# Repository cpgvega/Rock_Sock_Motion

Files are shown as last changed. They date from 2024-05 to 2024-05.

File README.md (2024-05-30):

# Rock'em Sock'em Motion

## Authors
- [Jonathan Meng] - [mengjc@umich.edu](mailto:mengjc@umich.edu)
- [Christian Reed] - [chrireed@umich.edu](mailto:chrireed@umich.edu)
- [Christian Vega](https://github.com/cpgvega) - [email@example.com](mailto:cpvega@umich.edu)

## Prerequisites/Materials
- STMicroelectronics Nucleo Board - L4R5ZI
- STMicroelectronics Nucleo Board - F446RE
- Servo Motors
- Bread boards
- Wiring
- [H-Bridge](https://www.amazon.com/Driver-Module-H-Bridge-Stepper-Control/dp/B07RWLKCH3)
- [Door Lock Actuator](https://www.amazon.com/Zone-2-Pack-Universal-Power-Actuator/dp/B00PWLJ2OC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)
- [DDR PS2 Pad](https://www.amazon.com/Dance-Revolution-Regular-Playstation2-Playstation-2/dp/B000GF7KAW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)
- [XBee Moduel](https://www.amazon.com/Module-Upgrade-Zigbee-Wireless-Transmission/dp/B0CP78Y1BF)

## Member Contribution
### Jonathan Meng
1.	Servo calibration and Pulse Width Modulation Set-Up
2.	Software for UART and Start Button Functionality
3.	Code Integration of Individual Software Components into Final Project
4.	Accelerometer and XBee ADC Integration and Debugging
5.	Mechanical Design and System Integration of Servos
6.	Mechanical Design and System Integration of DC Stepper Motors
7.	Mechanical Design and System Integration of Rock ‘Em Sock ‘Em Platform
8.	XBee Setup and Communication Protocol Debugging
9.	UART Debug, TX/RX System Integration, and STMBoard Testing
10.	Accelerometer and XBee ADC Integration and Debugging
11.	STMBoard Integration and Pinout Discovery
12.	Software for UART and Start Button Functionality

### Christian Reed
1.	H-Bridge and DC Stepper Motor Integration
2.	Servo calibration and Pulse Width Modulation Set-Up
3.	Mechanical Design and System Integration of PS2 DDR Pad
4.	Mechanical Design and System Integration of Servos
5.	Mechanical Design and System Integration of DC Stepper Motors
6.	Circuit Building of Hand-Held Accelerometers
7.	Accelerometer and XBee ADC Integration and Debugging
8.	Software for XBee Communication and PS2 Functionality
9.	Software for UART and Start Button Functionality
10.	XBee Setup and Communication Protocol Debugging
11.	Accelerometer and XBee ADC Integration and Debugging
12.	STMBoard Integration and Pinout Discovery

### Christian Vega
1.	Mounting of Hardware
2.	Schematic Diagramming
3.	H-Bridge and DC Stepper Motor Integration
4.	Mechanical Design and System Integration of PS2 DDR Pad
5.	Software for PS2 Polling and Bit Extraction
6.	Mechanical Design and System Integration of Servos
7.	Mechanical Design and System Integration of DC Stepper Motors
8.	Mechanical Design and System Integration of Rock ‘Em Sock ‘Em Platform
9.	System Integration of PS2 DDR Pad
10.	CAD, 3D Printing, and System Integration of Hand-Held Accelerometers
11.	STMBoard Integration and Pinout Discovery
12.	Software for PS2 Polling and Bit Extraction

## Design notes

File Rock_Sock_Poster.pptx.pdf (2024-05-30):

# Rock’ Sock’ and otion

## Christian Reed, Christian Vega, Jonathan Meng

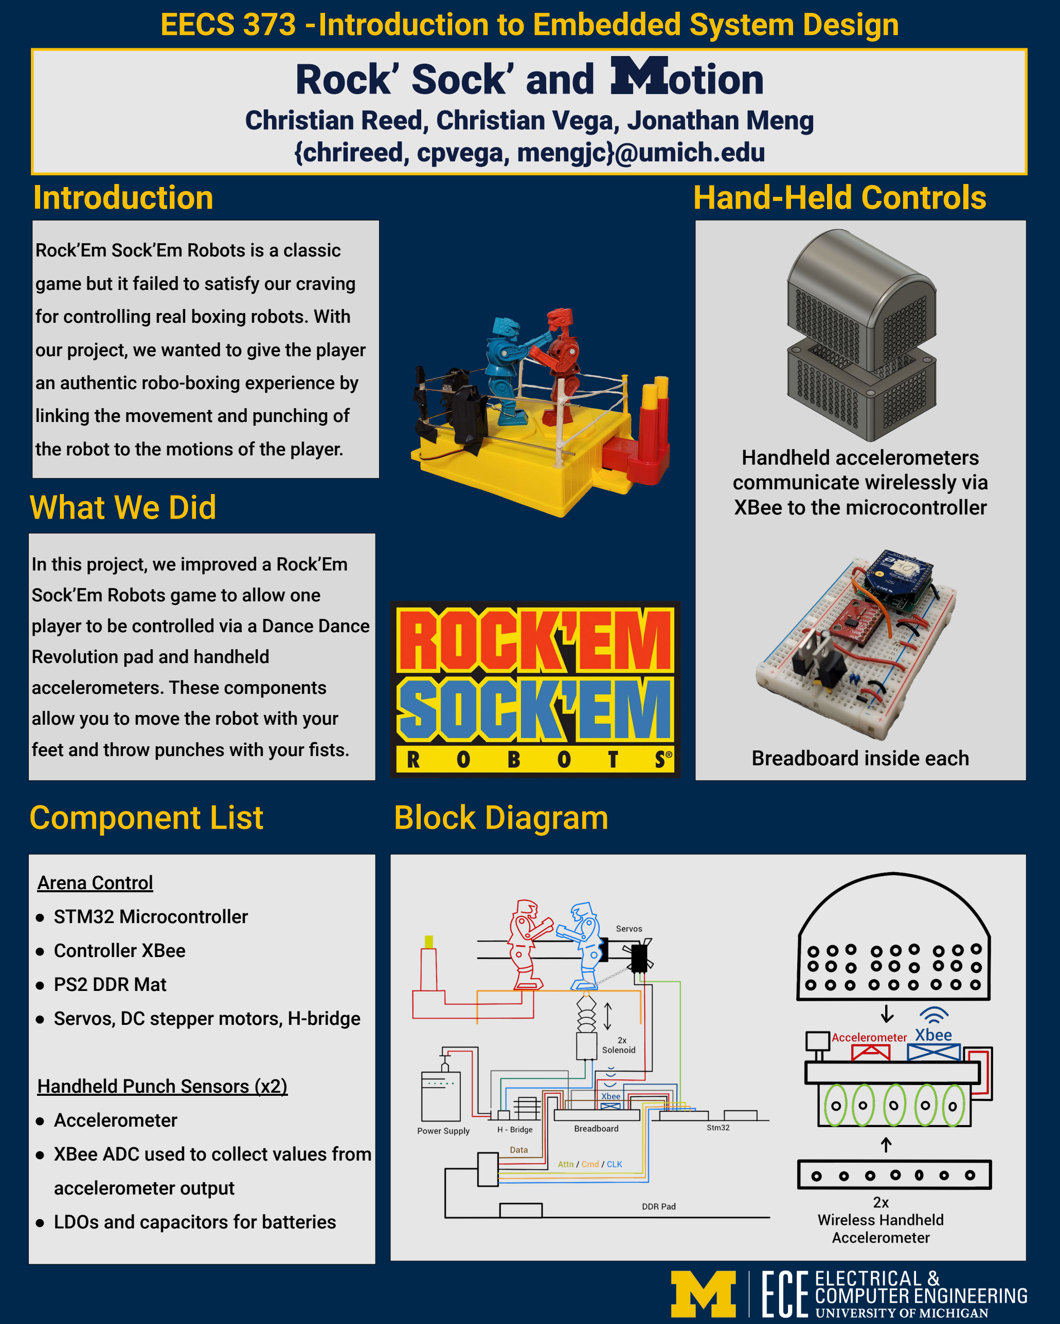
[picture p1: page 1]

## {chrireed, cpvega, mengjc}@umich.edu

# EECS 373 -Introduction to Embedded System Design

# Introduction

Component List | Block Diagram

# What We Did

Handheld accelerometers
communicate wirelessly via XBee to the microcontroller

Rock’Em Sock’Em Robots is a classic

game but it failed to satisfy our craving

for controlling real boxing robots. With

our project, we wanted to give the player

an authentic robo-boxing experience by

linking the movement and punching of

the robot to the motions of the player.

# Hand-Held Controls

In this project, we improved a Rock’Em Sock’Em Robots game to allow one player to be controlled via a Dance Dance Revolution pad and handheld accelerometers. These components allow you to move the robot with your feet and throw punches with your fists.

Arena Control

- STM32 Microcontroller
- Controller XBee
- PS2 DDR Mat
- Servos, DC stepper motors, H-bridge

Handheld Punch Sensors (x2)

- Accelerometer
- XBee ADC used to collect values from

accelerometer output

- LDOs and capacitors for batteries

Breadboard inside each

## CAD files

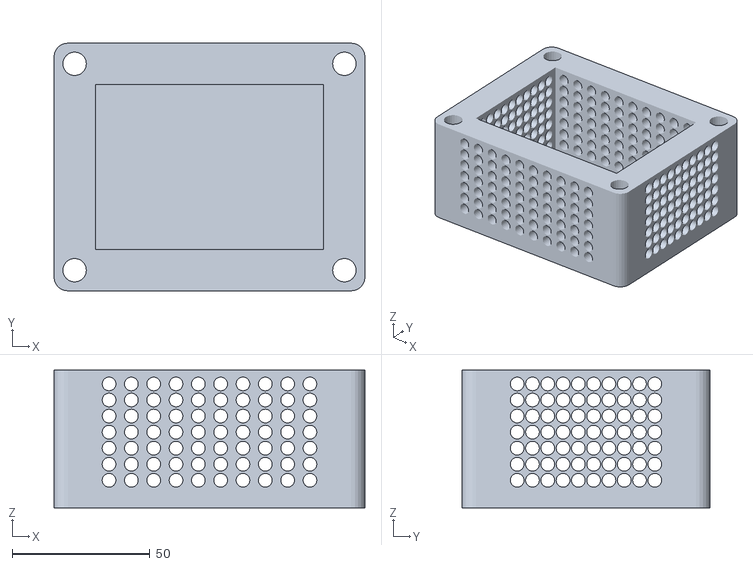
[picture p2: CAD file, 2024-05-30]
CAD Designs/Capsule_Accelorometer v9.obj
113.0 x 90.0 x 50.0

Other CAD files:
CAD Designs/RSM_3d_model v1.f3d

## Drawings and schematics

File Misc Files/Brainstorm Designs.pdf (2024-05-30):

# Brainstorm Designs

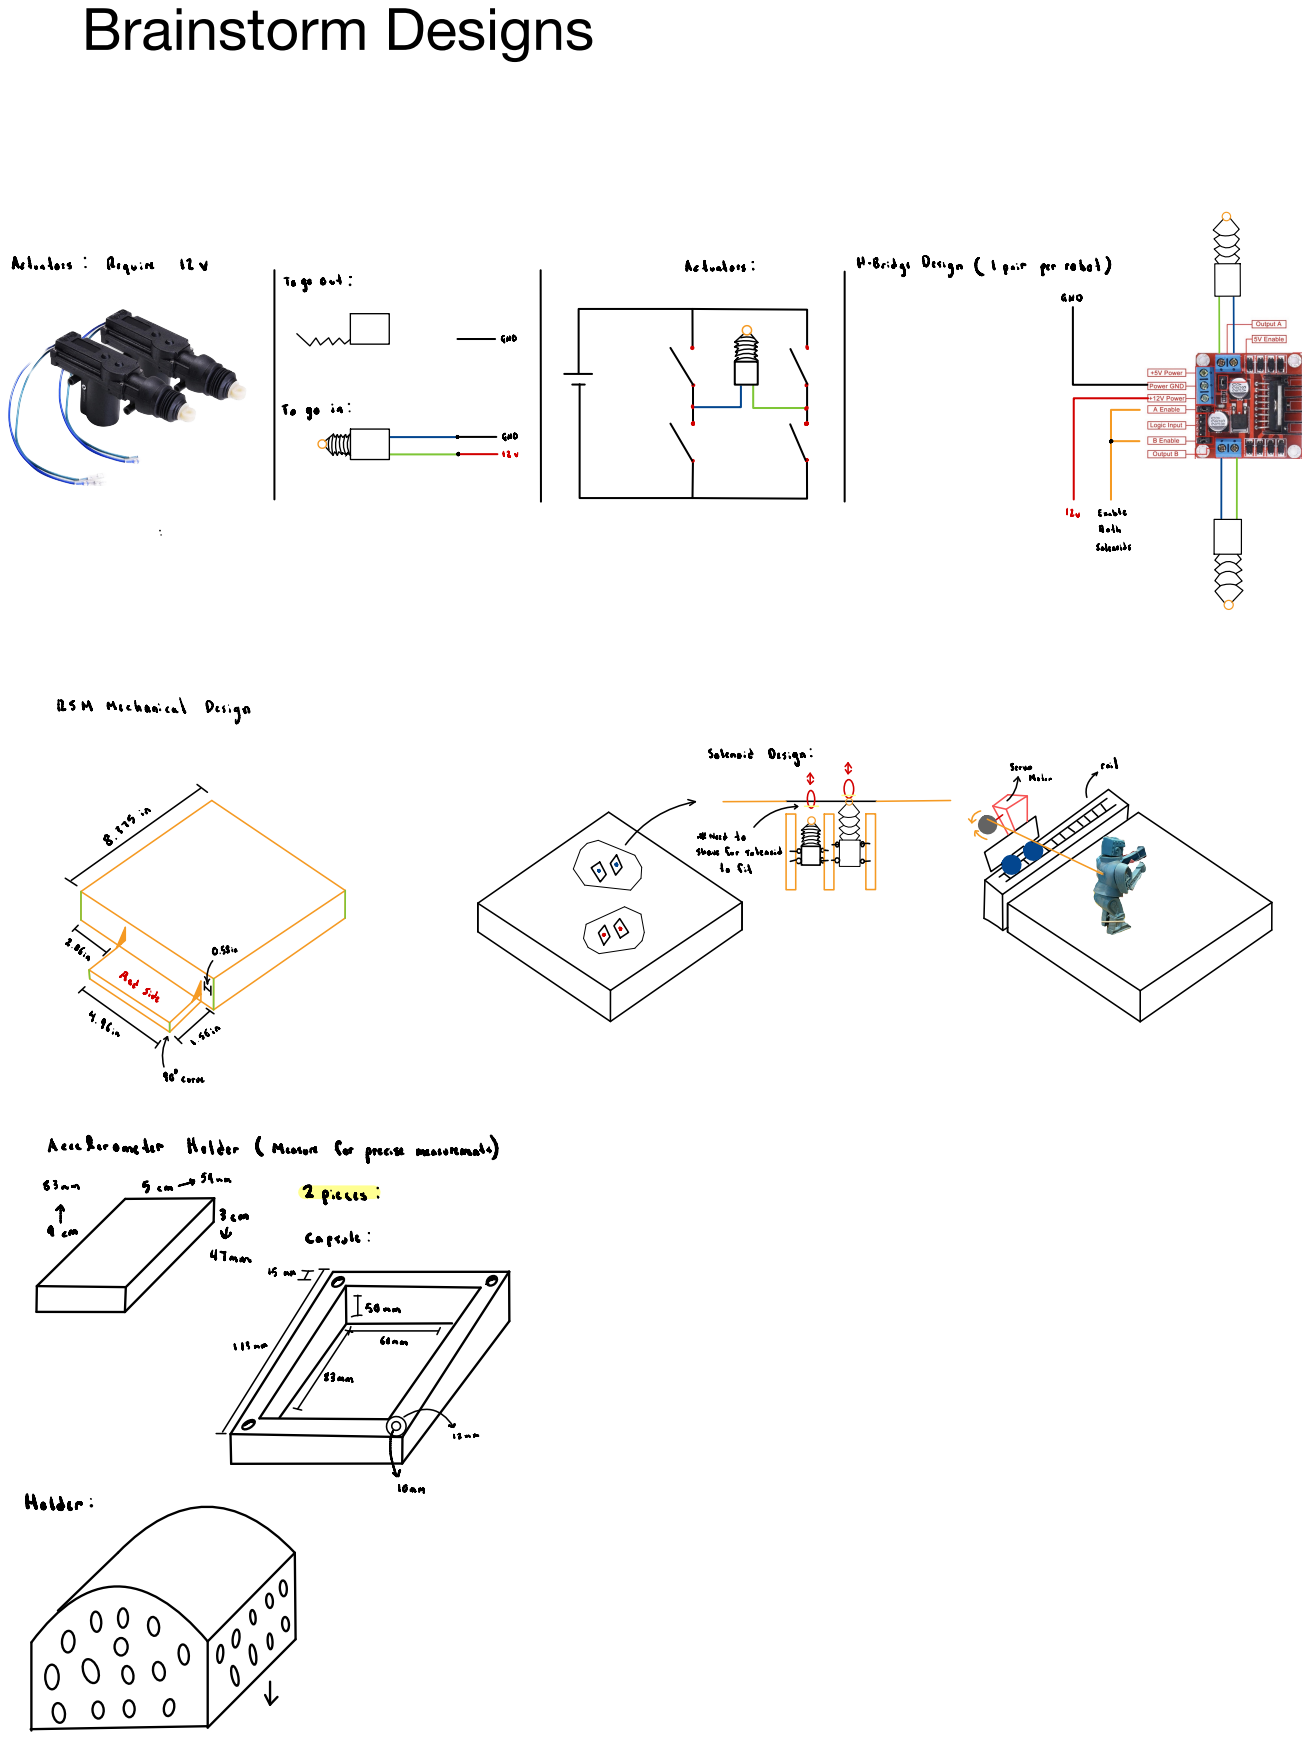
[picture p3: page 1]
Actuators :; Require; H-Bridge Design (1 pair per robot) To go out :; GND; Enable; Both .; Solenoids; Mechanical Design; Solenoid; Design :; Serve; rail; Motor; to Sit; ↳sim; goo curve; 83 man; 2 pieces :; Capsule :; Holder :

* Need to
Shave for solenoid

Accelerometer Holder (Measure for precise measurements)

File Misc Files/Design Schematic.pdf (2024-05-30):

# Design Schematic

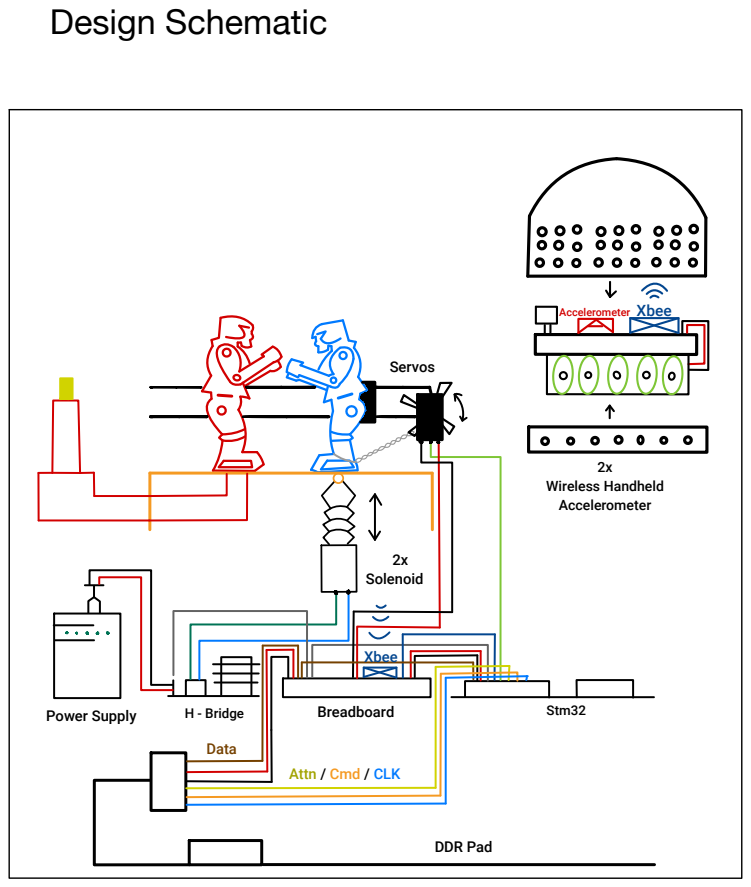
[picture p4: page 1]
Power Supply; H - Bridge; Breadboard; Stm32; 2x Solenoid; Servos; DDR Pad; Data; Xbee; 2x Wireless Handheld Accelerometer; Accelerometer

Attn / Cmd / CLK

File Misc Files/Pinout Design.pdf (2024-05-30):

# Stm32 Wall

# Outlet

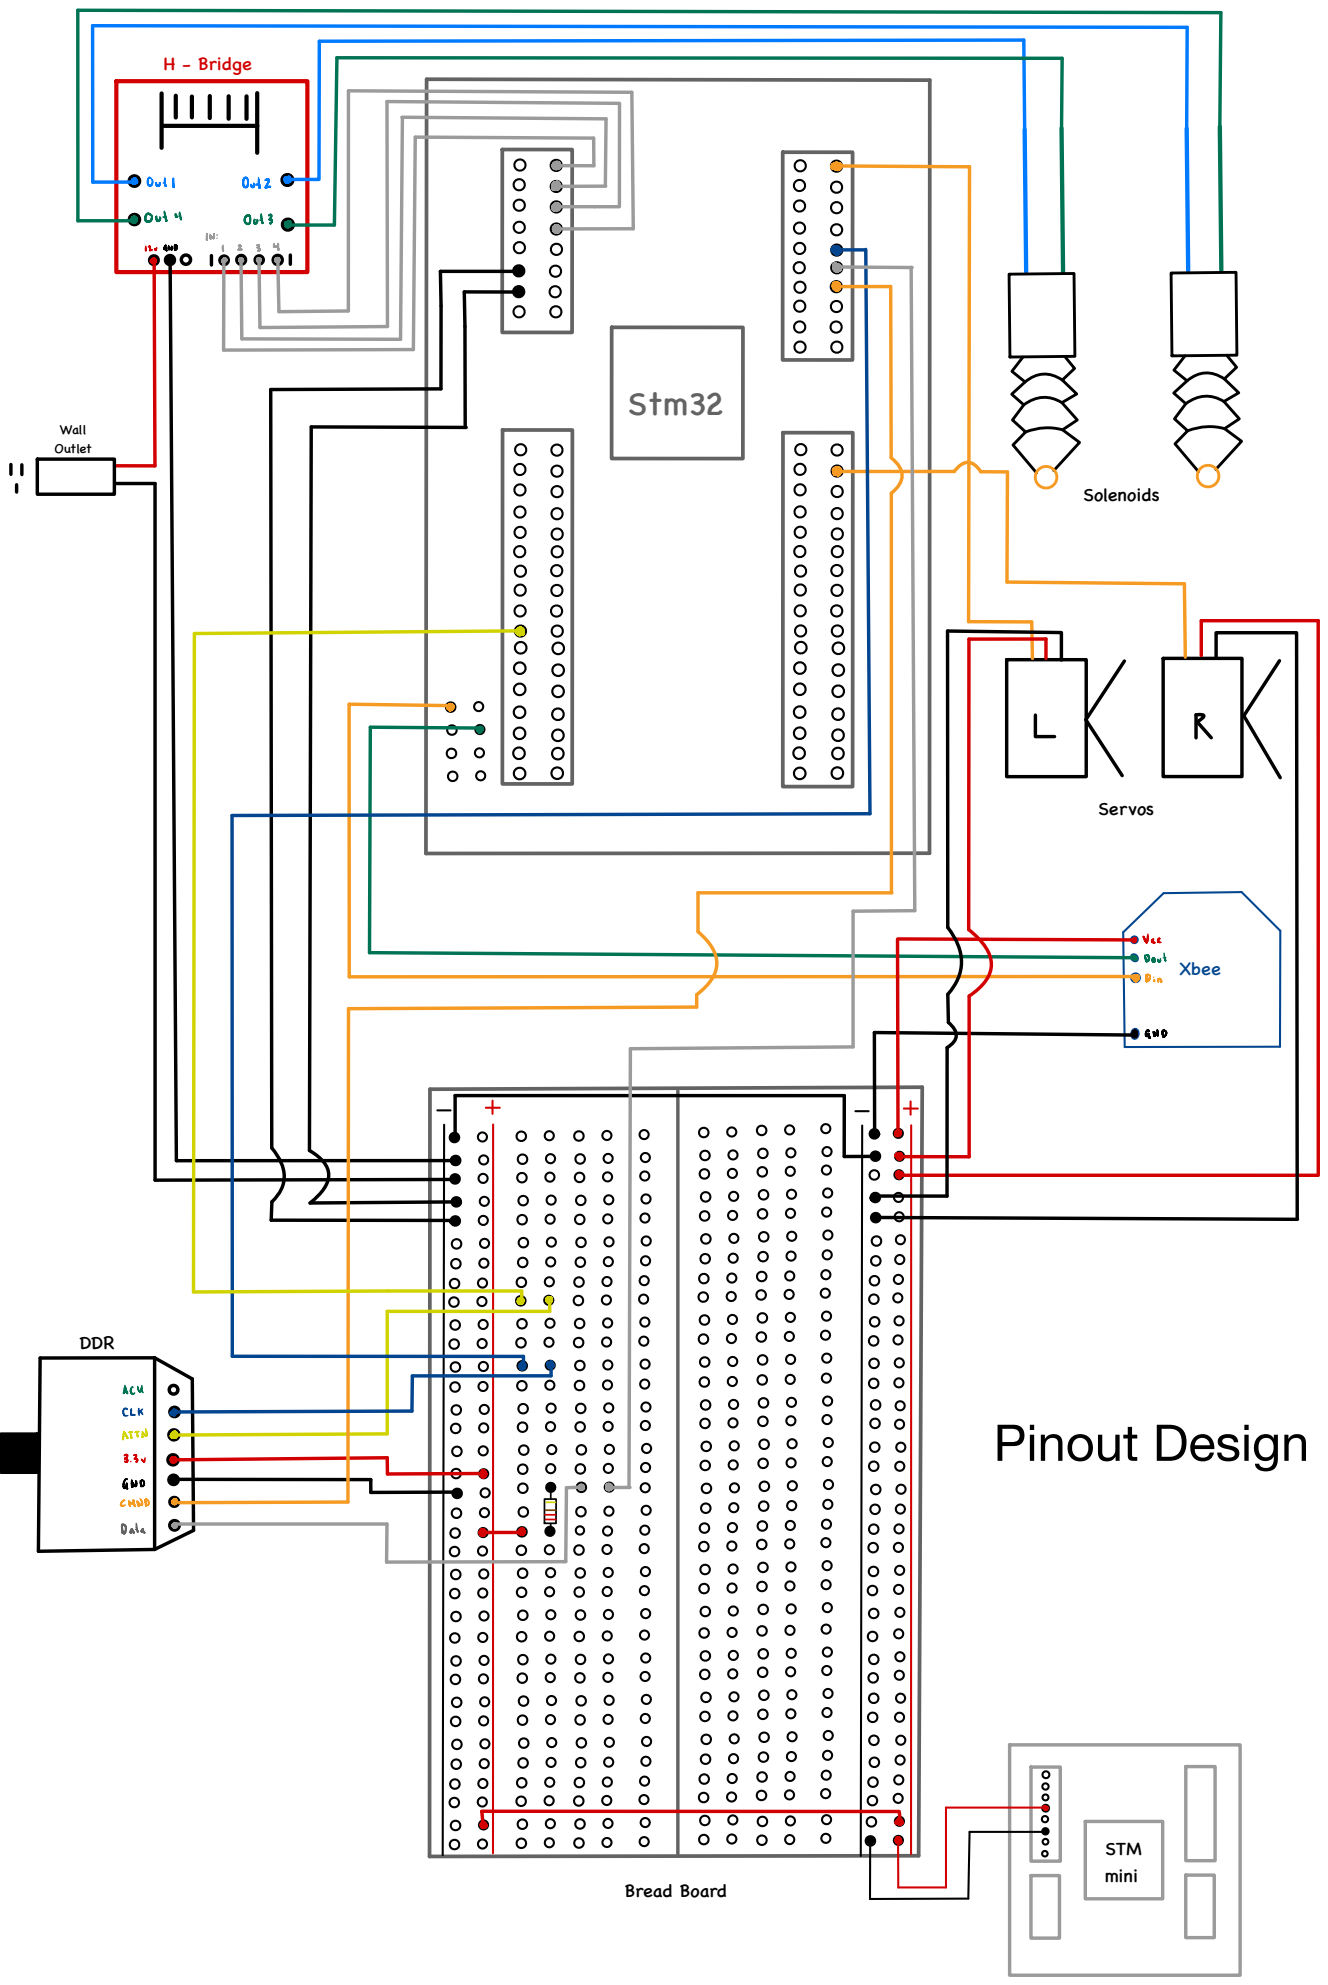
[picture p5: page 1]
Xbee; STM mini; H - Bridge; Solenoids; Bread Board; Servos; DDR; Pinout Design; Out1; Out &; · Out 4; Out 38; 12v GND; · Dout; ⑧ Din; · GND; CLK; ATTN; GND; CMND; Data

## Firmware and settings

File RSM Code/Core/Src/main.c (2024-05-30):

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
/* Includes ------------------------------------------------------------------*/
#include "main.h"

SPI_HandleTypeDef hspi1;

TIM_HandleTypeDef htim1;
TIM_HandleTypeDef htim4;

UART_HandleTypeDef huart1;

/* USER CODE BEGIN PV */
// First 5 bytes of DDR pad -> 01 - 03: Header (Will Not Change) & 04 - 05: Digital BTN Values
uint8_t ddr_tx[5] =  {0x01, 0x42, 0x00, 0x00, 0x00};
uint8_t ddr_rx[5];
// ddr pad buffer for eliminating noise (update both when changing)
int ddr_buf_size = 4;
char ddr_buf[4];

int num_u = 0;
int num_d = 0;
int num_l = 0;
int num_r = 0;
int num_s = 0;
int num_x = 0;

int uart_tx_size = 19;
int uart_rx_size = 24;
int punchThreshold = 750;
int leftPunch = 0;
int rightPunch = 0;
int leftPunchDone = 1;
int rightPunchDone = 1;
/* USER CODE END PV */

void SystemClock_Config(void);
static void MX_GPIO_Init(void);
static void MX_SPI1_Init(void);
static void MX_TIM4_Init(void);
static void MX_TIM1_Init(void);
static void MX_USART1_UART_Init(void);
/* USER CODE BEGIN 0 */

/*
 * poll_accell: sends a polling instruction to one of the two handheld XBEE
 * + accelerometer combos. The XBEE returns a packet of data which poll_accel
 * parses and returns the ADC value from the accelerometer
 * */
int poll_accel(uint8_t tx_buf[]){
	uint8_t rx_buf[uart_rx_size];
	//HAL_GPIO_WritePin(GPIOC, GPIO_PIN_9, GPIO_PIN_RESET);
	HAL_StatusTypeDef valT = HAL_UART_Transmit(&huart1, &tx_buf[0], uart_tx_size, 50);
	HAL_StatusTypeDef valR = HAL_UART_Receive(&huart1, &rx_buf[0], uart_rx_size, 100);
	if(valR == HAL_TIMEOUT) {
		//Debug using GPIO
		//HAL_GPIO_WritePin(GPIOC, GPIO_PIN_9, GPIO_PIN_SET);
		/*
		 * Occasionally the XBEE will give garbled data that sends UART into
		 * an infinite timeout loop, these statements are used to reset it
		*/
		HAL_UART_DeInit(&huart1);
		HAL_UART_Init(&huart1);
		return 0;
	}
	return (rx_buf[uart_rx_size - 3] << 8 | rx_buf[uart_rx_size - 2]);
}


// used by punch_logic to activate the left, right, or left and right solenoids
void punch(int left, int right) {
	if(right) {
		HAL_GPIO_WritePin(GPIOC, GPIO_PIN_9, GPIO_PIN_RESET);
		HAL_GPIO_WritePin(GPIOC, GPIO_PIN_8, GPIO_PIN_SET);
	}
	if(left){
		HAL_GPIO_WritePin(GPIOC, GPIO_PIN_11, GPIO_PIN_RESET);
		HAL_GPIO_WritePin(GPIOC, GPIO_PIN_10, GPIO_PIN_SET);
	}
	HAL_Delay(40);
	if(right) {
		HAL_GPIO_WritePin(GPIOC, GPIO_PIN_8, GPIO_PIN_RESET);
		HAL_GPIO_WritePin(GPIOC, GPIO_PIN_9, GPIO_PIN_SET);
	}
	if(left) {
		HAL_GPIO_WritePin(GPIOC, GPIO_PIN_10, GPIO_PIN_RESET);
		HAL_GPIO_WritePin(GPIOC, GPIO_PIN_11, GPIO_PIN_SET);
	}
	HAL_Delay(100);
	HAL_GPIO_WritePin(GPIOC, GPIO_PIN_8, GPIO_PIN_RESET);
	HAL_GPIO_WritePin(GPIOC, GPIO_PIN_9, GPIO_PIN_RESET);
	HAL_GPIO_WritePin(GPIOC, GPIO_PIN_10, GPIO_PIN_RESET);
	HAL_GPIO_WritePin(GPIOC, GPIO_PIN_11, GPIO_PIN_RESET);
	leftPunch = 0;
	rightPunch = 0;
	return;
}

// takes in the left and right accel values and activates solenoids using punch
void punch_logic(int left_accel_val, int right_accel_val) {
	if(leftPunchDone) {
				if(left_accel_val > punchThreshold) {
					leftPunch = 1;
					leftPunchDone = 0;
				}
			} else {
				if(left_accel_val < punchThreshold) {
					leftPunchDone = 1;
				}
			}
			if(rightPunchDone) {
				if(right_accel_val > punchThreshold) {
					rightPunch = 1;
					rightPunchDone = 0;
				}
			} else {
				if(right_accel_val < punchThreshold) {
					rightPunchDone = 1;
				}
			}

			if (leftPunch | rightPunch) {
				punch(leftPunch, rightPunch);
			}
	return;
}

/*
 * This functions breaks down the 4th byte extracted from the DDR pad
 * and return a char of the designated direction
 */
char bit_extract (uint8_t ddr_byte_3, uint8_t ddr_byte_4) {
	// Grab up
	uint8_t up = (ddr_byte_3 << 3) >> 7;
	uint8_t right = (ddr_byte_3 << 2) >> 7;
	uint8_t left = (ddr_byte_3 << 0) >> 7;
	uint8_t down = (ddr_byte_3 << 1) >> 7;
	uint8_t circ = (ddr_byte_4 << 2) >> 7;

	up &= (0b1);
	right &= (0b1);
	left &= (0b1);
	down &= (0b1);
	circ &= (0b1);
	if (!circ)
		return 's';
	else if(!up)
		return 'u';
	else if (!right)
		return 'r';
	else if (!left)
		return 'l';
	else if (!down)
		return 'd';

	return 'x';
}

// polls the ddr pad and loads result in ddr_rx
char poll_ddr(){
	// DDR Pad Data Request - These values (ddr_rx[4] & ddr_rx[5] will be used for the movement)
	// RESET ATTN line before sent/receive
	HAL_GPIO_WritePin(GPIOB, GPIO_PIN_6, GPIO_PIN_RESET);

	// Transmit/Receive byte by byte
	HAL_SPI_TransmitReceive(&hspi1, &ddr_tx[0], &ddr_rx[0], 1, 100);
	HAL_SPI_TransmitReceive(&hspi1, &ddr_tx[1], &ddr_rx[1], 1, 100);
	HAL_SPI_TransmitReceive(&hspi1, &ddr_tx[2], &ddr_rx[2], 1, 100);
	HAL_SPI_TransmitReceive(&hspi1, &ddr_tx[3], &ddr_rx[3], 1, 100);
	HAL_SPI_TransmitReceive(&hspi1, &ddr_tx[4], &ddr_rx[4], 1, 100);

	// SET ATTN line after sent/receive
	HAL_GPIO_WritePin(GPIOB, GPIO_PIN_6, GPIO_PIN_SET);

	//calculate directional output using an 8 poll buffer
	char direction = bit_extract(ddr_rx[3], ddr_rx[4]);

	//update counts
	if (direction == 'u')
		num_u += 1;
	else if (direction == 'd')
		num_d += 1;
	else if (direction == 'l')
		num_l += 1;
	else if (direction == 'r')
		num_r += 1;
	else if (direction == 's')
		num_s += 1;
	else
		num_x += 1;

	if (ddr_buf[ddr_buf_size - 1] == 'u')
		num_u -= 1;
	else if (ddr_buf[ddr_buf_size - 1] == 'd')
		num_d -= 1;
	else if (ddr_buf[ddr_buf_size - 1] == 'l')
		num_l -= 1;
	else if (ddr_buf[ddr_buf_size - 1] == 'r')
		num_r -= 1;
	else if (ddr_buf[ddr_buf_size - 1] == 's')
			num_s -= 1;
	else
		num_x -= 1;

	//update buffer
	for(int i = ddr_buf_size - 1; i > 0; i--){
		ddr_buf[i] = ddr_buf[i-1];
	}
	ddr_buf[0] = direction;

	//return if majority
	int majority = ddr_buf_size/2 + 1;
	if (num_u >= majority)
		return 'u';
	else if (num_d >= majority)
		return 'd';
	else if (num_l >= majority)
		return 'l';
	else if (num_r >= majority)
		return 'r';
	else if (num_s >= majority)
		return 's';
	else
		return 'x';

}

// FOR THE CODE BELOW YOU MIGHT NEED TO HAVE IT STOP ACCEPTING INPUT IF THE X OR Y DIRECTION REACHES ITS MINIMUM/MAXIMUM

// Increase or Decrease left Servo position
int left_pos_change (char dir) {
	int extend = 2100;
	int dodge = 1900;
	int retract = 1500;
	int neutral = 1700;
	// Change Servo Position based on input from DDR pad
	switch(dir) {
	case 'u':
		return extend;
	case 'd':
		return retract;
	case 'l':
		return retract;
	case 'r':
		return dodge;
	default:
		return neutral;
	}
}

// Increase or Decrease right Servo position
int right_pos_change (char dir) {
	int extend = 900;
	int dodge = 1100;
	int retract = 1500;
	int neutral = 1300;
	// Change Servo Position based on input from DDR pad
	switch(dir) {
	case 'u':
		return extend;
	case 'd':
		return retract;
	case 'l':
		return dodge;
	case 'r':
		return retract;
	default:
		return neutral;
	}
}


// takes ddr data in rx_buf and writes to the servos
void move(char direction) {

	// Send Info to left and right servos
	int left_pos = left_pos_change(direction);
	int right_pos = right_pos_change(direction);
	//leftpos = 1100 rightpos = 1900 is back
	//leftpos = 1900 rightpos = 1100 is front
	__HAL_TIM_SetCompare(&htim4, TIM_CHANNEL_3, left_pos);
	__HAL_TIM_SetCompare(&htim1, TIM_CHANNEL_1, right_pos);
	return;
}

/* USER CODE END 0 */

/**
  * @brief  The application entry point.
  * @retval int
  */
int main(void)
{
  /* MCU Configuration--------------------------------------------------------*/

  /* Reset of all peripherals, Initializes the Flash interface and the Systick. */
  HAL_Init();

  /* Configure the system clock */
  SystemClock_Config();

  /* Initialize all configured peripherals */
  MX_GPIO_Init();
  MX_SPI1_Init();
  MX_TIM4_Init();
  MX_TIM1_Init();
  MX_USART1_UART_Init();
  /* USER CODE BEGIN 2 */

	//Reset all GPIO pins
	HAL_GPIO_WritePin(GPIOC, GPIO_PIN_8, GPIO_PIN_RESET);
	HAL_GPIO_WritePin(GPIOC, GPIO_PIN_9, GPIO_PIN_RESET);
	HAL_GPIO_WritePin(GPIOC, GPIO_PIN_10, GPIO_PIN_RESET);
	HAL_GPIO_WritePin(GPIOC, GPIO_PIN_11, GPIO_PIN_RESET);

	//Set buffers to XBEE polling commands
	uint8_t left_tx_buf[uart_tx_size];
	uint8_t right_tx_buf[uart_tx_size];

	//LEFT HAND "OK TAPE"
	left_tx_buf[0] = 0x7E;
	left_tx_buf[1] = 0x00;
	left_tx_buf[2] = 0x0F;
	left_tx_buf[3] = 0x17;
	left_tx_buf[4] = 0x01;
	left_tx_buf[5] = 0x00;
	left_tx_buf[6] = 0x13;
	left_tx_buf[7] = 0xA2;
	left_tx_buf[8] = 0x00;
	left_tx_buf[9] = 0x40;
	left_tx_buf[10] = 0xDC;
	left_tx_buf[11] = 0xEB;
	left_tx_buf[12] = 0x52;
	left_tx_buf[13] = 0xFF;
	left_tx_buf[14] = 0xFE;
	left_tx_buf[15] = 0x02;
	left_tx_buf[16] = 0x69;
	left_tx_buf[17] = 0x73;
	left_tx_buf[18] = 0xFE;

	//RIGHT HAND "OK"
	right_tx_buf[0] = 0x7E;
	right_tx_buf[1] = 0x00;
	right_tx_buf[2] = 0x0F;
	right_tx_buf[3] = 0x17;
	right_tx_buf[4] = 0x01;
	right_tx_buf[5] = 0x00;
	right_tx_buf[6] = 0x13;
	right_tx_buf[7] = 0xA2;
	right_tx_buf[8] = 0x00;
	right_tx_buf[9] = 0x40;
	right_tx_buf[10] = 0xDC;
	right_tx_buf[11] = 0x2F;
	right_tx_buf[12] = 0x3A;
	right_tx_buf[13] = 0xFF;
	right_tx_buf[14] = 0xFE;
	right_tx_buf[15] = 0x02;
	right_tx_buf[16] = 0x69;
	right_tx_buf[17] = 0x73;
	right_tx_buf[18] = 0xD2;

	// Dance Dance Revolution Pad Set-up/Variables

	// This is for the Attention Line for DDR pad (GPIO_Output)
	// *PLEASE NOTE* - the ATTN Line must be RESET before a Transmit/Receive through SPI and then must be SET after
	HAL_GPIO_WritePin(GPIOB, GPIO_PIN_6, GPIO_PIN_SET);
	for(int i = 0; i < ddr_buf_size; i++){
		ddr_buf[i] = 'x';
		num_x += 1;
	}

	// Start up PWM Timers
	HAL_TIM_PWM_Start(&htim4, TIM_CHANNEL_3);
	HAL_TIM_PWM_Start(&htim1, TIM_CHANNEL_1);

	char game_start = 'x';
	while(game_start != 's'){
		game_start = poll_ddr();
	}
	while(game_start == 's'){
		game_start = poll_ddr();
	}
  /* USER CODE END 2 */

  /* Infinite loop */
  /* USER CODE BEGIN WHILE */
	while (1)
	{
		// Left and Right Accelerometer Values
		int left_accel_val = poll_accel(left_tx_buf);
		int right_accel_val = poll_accel(right_tx_buf);
		punch_logic(left_accel_val, right_accel_val);
		char direction = poll_ddr();
		if(direction == 's') {

			// Toggle On/Off
			while(direction == 's'){
				direction = poll_ddr();
			}
			while(direction != 's'){
				direction = poll_ddr();
			}
			while(direction == 's'){
				direction = poll_ddr();
			}

		}
		move(direction);

    /* USER CODE END WHILE */

    /* USER CODE BEGIN 3 */

	}
  /* USER CODE END 3 */
}

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


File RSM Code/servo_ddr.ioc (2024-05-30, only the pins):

Mcu.UserName=STM32L4R5ZITxP
PA0.Signal=S_TIM2_CH1
PA1.Signal=ADCx_IN6
PA10.Signal=USB_OTG_FS_ID
PA3.Signal=ADCx_IN8
PA4.Signal=SPI1_NSS
PA5.Signal=SPI1_SCK
PA6.Signal=SPI1_MISO
PA7.Signal=SPI1_MOSI
PA8.Signal=USB_OTG_FS_SOF
PA9.Signal=USB_OTG_FS_VBUS
PB1.Signal=ADCx_IN16
PB10.Signal=S_TIM2_CH3
PB12.Signal=SAI2_FS_A
PB13.Signal=SAI2_SCK_A
PB14.Signal=S_TIM15_CH1
PB15.Signal=SAI2_SD_A
PB2.Signal=COMP1_INP
PB5.Signal=SPI3_MOSI
PB6.Signal=GPIO_Output
PB8.Signal=S_TIM4_CH3
PC0.Signal=ADCx_IN1
PC1.Signal=ADCx_IN2
PC10.Signal=GPIO_Output
PC11.Signal=GPIO_Output
PC12.Signal=SDMMC1_CK
PC13.Signal=SYS_WKUP2
PC2.Signal=ADCx_IN3
PC3.Signal=ADCx_IN4
PC4.Signal=ADCx_IN13
PC5.Signal=ADCx_IN14
PC6.Signal=SAI2_MCLK_A
PC7.Signal=S_TIM3_CH2
PC8.Signal=GPIO_Output
PC9.Signal=GPIO_Output
PD0.Signal=CAN1_RX
PD2.Signal=SDMMC1_CMD
PD3.Signal=USART2_CTS
PD4.Signal=USART2_RTS
PD5.Signal=USART2_TX
PD6.Signal=USART2_RX
PD8.Signal=USART3_TX
PD9.Signal=USART3_RX
PE0.Signal=S_TIM4_ETR
PE10.Signal=TIM1_CH2N
PE11.Signal=S_TIM1_CH2
PE12.Signal=TIM1_CH3N
PE13.Signal=S_TIM1_CH3
PE14.Signal=TIM1_BKIN2
PE15.Signal=TIM1_BKIN
PE2.Signal=SAI1_MCLK_A
PE3.Signal=SAI1_SD_B
PE7.Signal=S_TIM1_ETR
PE8.Signal=TIM1_CH1N
PE9.Signal=S_TIM1_CH1
PF0.Signal=I2C2_SDA
PF1.Signal=I2C2_SCL
PF2.Signal=I2C2_SMBA
PF7.Signal=SAI1_MCLK_B
PG10.Signal=USART1_RX
PG7.Signal=LPUART1_TX
PG8.Signal=LPUART1_RX
PG9.Signal=USART1_TX

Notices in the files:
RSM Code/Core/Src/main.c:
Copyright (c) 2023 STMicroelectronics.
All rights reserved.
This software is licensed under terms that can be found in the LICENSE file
